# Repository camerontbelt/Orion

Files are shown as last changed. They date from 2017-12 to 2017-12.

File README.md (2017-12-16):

## A simple, portable USB power supply

The Orion is a simple power module to convert a USB power source into a regulated positive and negative power supply for use with breadboards. It is designed to be small, and easily used with any five volt USB power brick. 

### What you will need
* USB B Mini cable
* 5V USB power brick

### Uses
* Opamps
* BJT circuits
* MOSFET circuits
* Any circuit you need a quick +/- voltage supply!






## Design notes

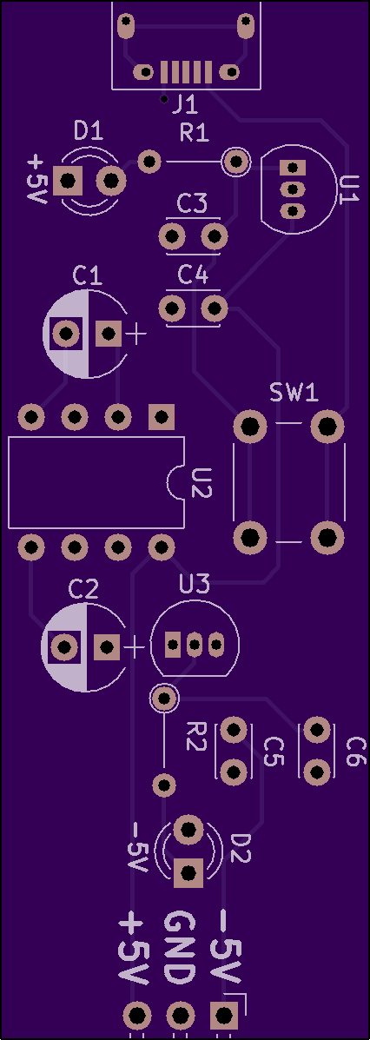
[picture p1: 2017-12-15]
Board Images/TOP.png

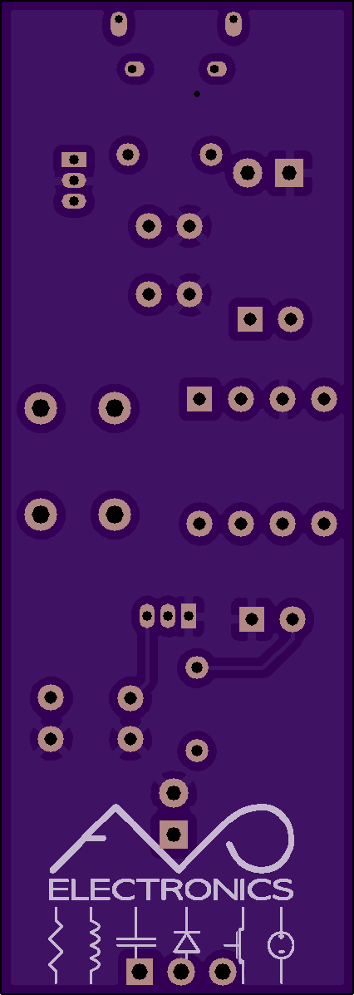
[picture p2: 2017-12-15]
Board Images/BOTTOM.png

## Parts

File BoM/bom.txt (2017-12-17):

BoM
ref	value	digikeypartnumber
c1	10uF	P19522CT-ND
c2	10uF	P19522CT-ND
c3	10uF	478-8042-1-ND
c4	10uF	478-8042-1-ND
c5	10uF	478-8042-1-ND
c6	10uF	478-8042-1-ND
d1	green	516-1792-1-ND
d2	green   516-1792-1-ND
j1	usb b micro	609-4618-1-ND
p1	right angle header pins	952-3615-ND
r1	1.5k	CF14JT1K50CT-ND
r2	1.5k    CF14JT1K50CT-ND
sw1	pushbutton on/off	CW181-ND
u1	+5vreg	296-20933-1-ND
u2	7660	LMC7660IN/NOPB-ND
u3	-5vreg	296-31456-1-ND

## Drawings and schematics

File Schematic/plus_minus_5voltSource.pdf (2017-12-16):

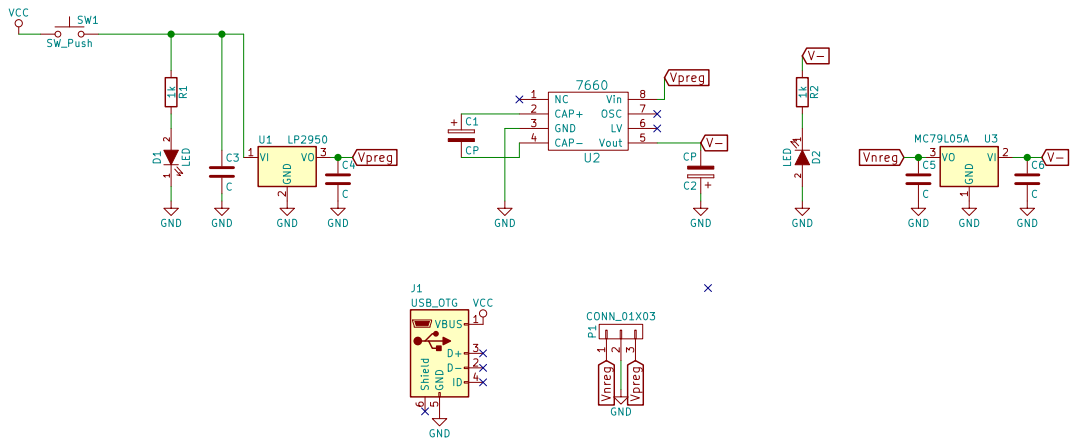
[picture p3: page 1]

1 VI 2 VO 3 MC79L05A U3 GND Vnreg V- Vnreg

File: plus_minus_5voltSource.sch Sheet: / AVO Electronics Cameron Belt +/-5V Portable supply

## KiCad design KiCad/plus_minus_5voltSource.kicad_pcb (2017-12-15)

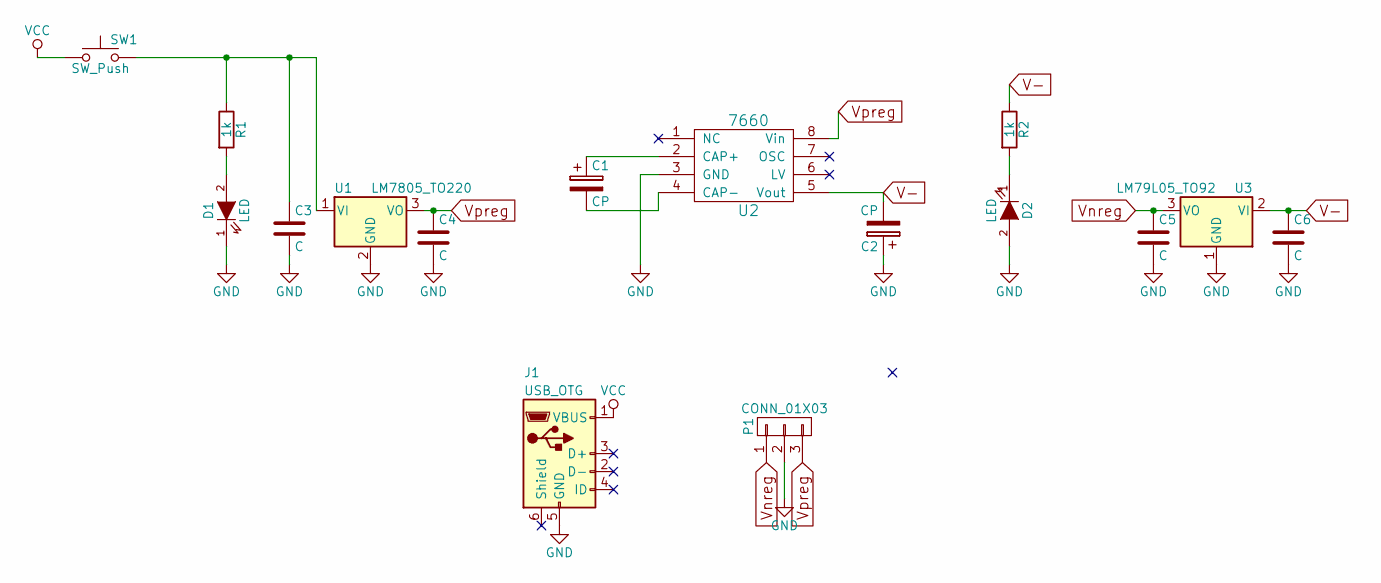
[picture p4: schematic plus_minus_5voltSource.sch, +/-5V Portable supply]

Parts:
C1, C2: CP; CP_Radial_D5.0mm_P2.50mm
C3, C4, C5, C6: C; C_Disc_D3.0mm_W2.0mm_P2.50mm
D1, D2: LED; LED_D3.0mm
J1: USB_OTG; USB_Micro-B
P1: CONN_01X03; Pin_Header_Angled_1x03_Pitch2.54mm
R1, R2: 1k; R_Axial_DIN0204_L3.6mm_D1.6mm_P5.08mm_Vertical
SW1: SW_Push; SW_PUSH_6mm
U1: LM7805_TO220; TO-92_Inline_Narrow_Oval
U2: 7660; DIP-8_W7.62mm
U3: LM79L05_TO92; TO-92_Inline_Narrow_Oval

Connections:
GND: C2.1, C3.2, C4.2, C5.2, C6.2, D1.1 (K), D2.2 (A), J1.5 (GND), P1.2, U1.2 (GND), U2.3 (GND), U3.1 (GND)
unnamed: C1.1, U2.2 (CAP+)
unnamed: C1.2, U2.4 (CAP-)
unnamed: C3.1, R1.1, SW1.2, U1.1 (VI)
unnamed: D1.2 (A), R1.2
unnamed: D2.1 (K), R2.2
V-: C2.2, C6.1, R2.1, U2.5 (Vout), U3.2 (VI)
VCC: J1.1 (VBUS), SW1.1
Vnreg: C5.1, P1.1, U3.3 (VO)
Vpreg: C4.1, P1.3, U1.3 (VO), U2.8 (Vin)

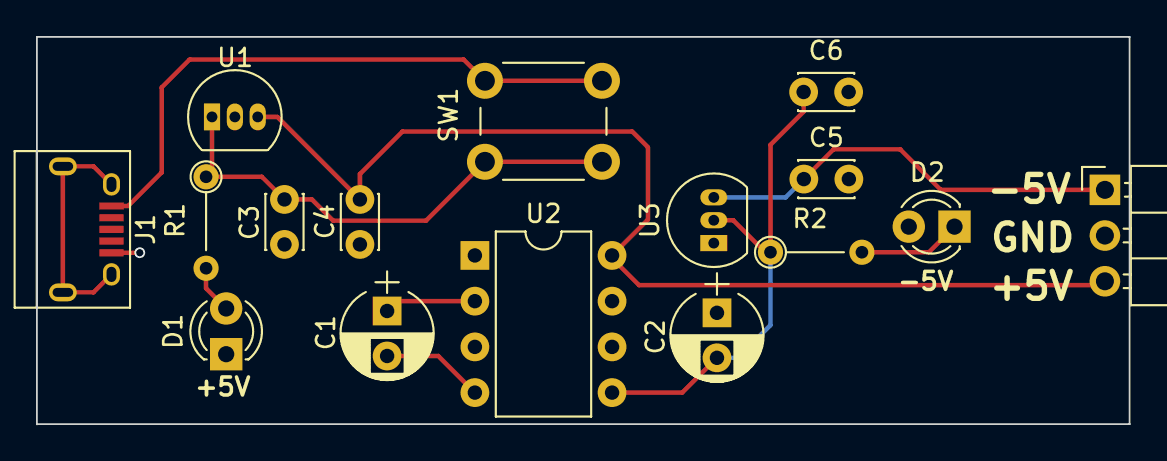
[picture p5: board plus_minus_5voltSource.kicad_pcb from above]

Board: 2 copper layers, 60.7 x 21.5 mm, 17 parts (1 on the bottom side), 10 nets.

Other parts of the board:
logo: logo

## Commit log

2017-12-12 Refactored schematic
    [plus_minus_5voltSource.sch]
2017-12-12 redesigned to have indicator leds, and voltage regulators
    [plus_minus_5voltSource.sch]
2017-12-12 added capacitors to voltage regulator lines.
    [plus_minus_5voltSource.sch]
2017-12-12 Added "made with kicad" to end of README.md
2017-12-12 Changed folder structure to reflect a more organized and standardized approach for electronics projects from now forward. * Board Images - contains rendered or real images of the board * BoM - contai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
    [plus_minus_5voltSource-B_CrtYd.gbr, plus_minus_5voltSource-B_Cu.gbr, plus_minus_5voltSource-B_Mask.gbr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]
2017-12-13 Removed old PCB layout from the pcb file.
    [plus_minus_5voltSource.kicad_pcb, plus_minus_5voltSource.sch]
2017-12-13 Removed old board images and added a new, blank bom text file. This will be used to add components in the future.
2017-12-13 Finalized schematic by adding the usb connector for power and ground.
    [plus_minus_5voltSource.sch]
2017-12-13 Added bom information, create netlist, and associated footprints with symbols.
    [plus_minus_5voltSource 3.sch]
2017-12-13 Added pcb file to project.
    [_saved_plus_minus_5voltSource.sch, plus_minus_5voltSource.kicad_pcb]
2017-12-13 Edited component association to be all through hole components.
    [_saved_plus_minus_5voltSource.sch, plus_minus_5voltSource.kicad_pcb]
2017-12-13 Edited BoM to have updated part numbers
    [_saved_plus_minus_5voltSource.sch]
2017-12-14 Formatted BOM.
    [plus_minus_5voltSource.kicad_pcb, plus_minus_5voltSource.sch]
2017-12-14 Finalized pcb by adding edge cut, and routing to pcb.
    [plus_minus_5voltSource.kicad_pcb]
2017-12-15 Added logo to PCB. Generated gerbers, and board images. Changed name of board to Orion.
    [plus_minus_5voltSource-B.CrtYd.gbr, plus_minus_5voltSource-B.Cu.gbl, plus_minus_5voltSource-B.Mask.gbs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]
2017-12-15 Changed name of board to Orion in README.md
2017-12-15 Edited voltage regulator part numbers to reflect actual part numbers. Added a schmatic folder with schematic pdf.
    [plus_minus_5voltSource.sch]
2017-12-15 Rotated board images 90 degrees.
2017-12-16 Added all components to the BoM.
2017-12-16 Changed schematic to reflect correct +5V regulator part number. Saved new PDF schematic sheet. Edited bom to have correct regulator digikey part number.
    [plus_minus_5voltSource.sch]
2017-12-17 Changed formatting of BoM to tabbed delimted text.
